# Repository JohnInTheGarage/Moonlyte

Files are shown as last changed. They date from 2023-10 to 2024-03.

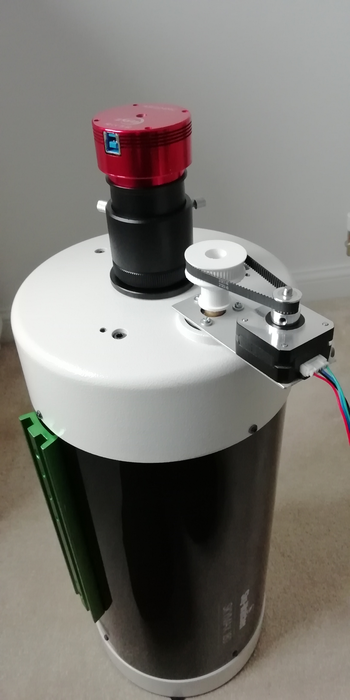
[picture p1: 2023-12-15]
photos etc/HardwareVersion2/BackView.jpg

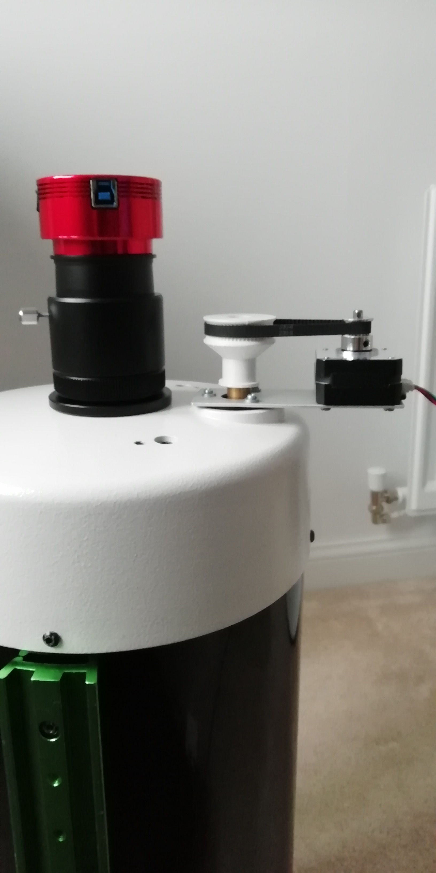
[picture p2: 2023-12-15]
photos etc/HardwareVersion2/SideView.jpg

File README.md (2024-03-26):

# Moonlyte
An electronic focuser for Skywatcher Skymax 180 telescopes, emulating the Moonlite protocol

This project is licensed under the terms of the MIT license.

Written in GO / Tinygo as I had not tried the language much. N.B. you will have to adjust settings.json
as it refers to a location for the GOROOT which is on my disk, not yours.

Uses a Pico microcontroller instead of the traditional Arduino, 
again because I had not used it and it was just collecting dust.  

This implements a basic subset of the Moonlite protocol which I found documented at 
https://indilib.org/media/kunena/attachments/1/HighResSteppermotor107.pdf
(Plus a "debug" output switch.  This is non-standard and should only be used to resolve problems as
it will send text to the host which the host is not expecting.)

Sadly, there is no non-volatile memory on the Pico, so the device will not remember where it was left if you power-off.
I plan to run the focuser back to position zero before power-off as my Host software (Ain Imager & Indigo Framework 
https://www.indigo-astronomy.org/index.html) does not let me use negative numbers for focuser position.  Maybe that's true of all focusers, don't know.

Even more sadly, Tinygo does not implement true concurrency - I had hoped to use the dual processor cores of the Pico, 
with one routine for Comms to the host and the other to drive the stepper but have had to interleave stepping with comms.  
A suitable future update would be to try using the PIO to drive the stepper instead of a separate core.

The physical parts could be improved too. The body is quite fiddly to assemble and prevents manual focusing, but as a first pass its working well.

2023-12-15 Version 2 hardware & slight update for software (mainly prevent "chugging" where the manual input causes the Stepper to be enabled and disabled rapidly)
V2 came about to make room for an Off-Axis Guider.

2024-01-24 Added Intervalometer and bigger box to hold the manual focus and Intervalometer on-off switches

2024-03-26 Added C version of the focuser code for proper multi-threading, reorganised code directories

<pre>
3d printing files Version 1 hardware:
FocuserV5.scad        Design file for Focuser body (OpenSCAD)
FocuserBox.scad       Design file for Box to hold electronics (OpenSCAD)
F.* STL files for the focuser body
</pre>
<pre>
3d printing files Version 2 hardware:
FocuserV6.scad        Design file for Focuser body (OpenSCAD)
FocuserBox.scad       (same as before)
F.* STL files for the focuser body
</pre>

<pre>
Driver module from https://www.amazon.co.uk/dp/B0893DPSJL 
Stepper motor from https://www.amazon.co.uk/dp/B08DCGHLYP. 
</pre>

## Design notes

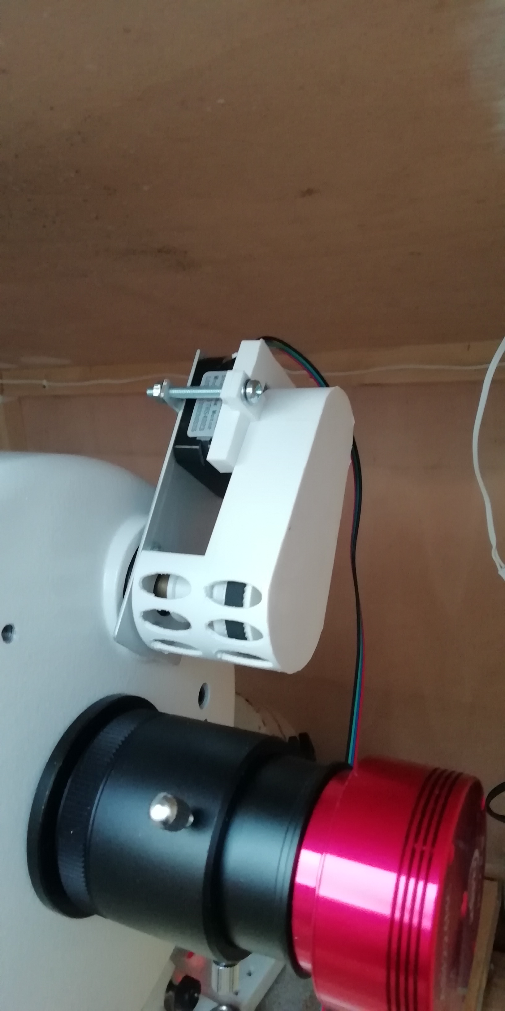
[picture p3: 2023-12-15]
photos etc/HardwareVersion2/WithCover.jpg

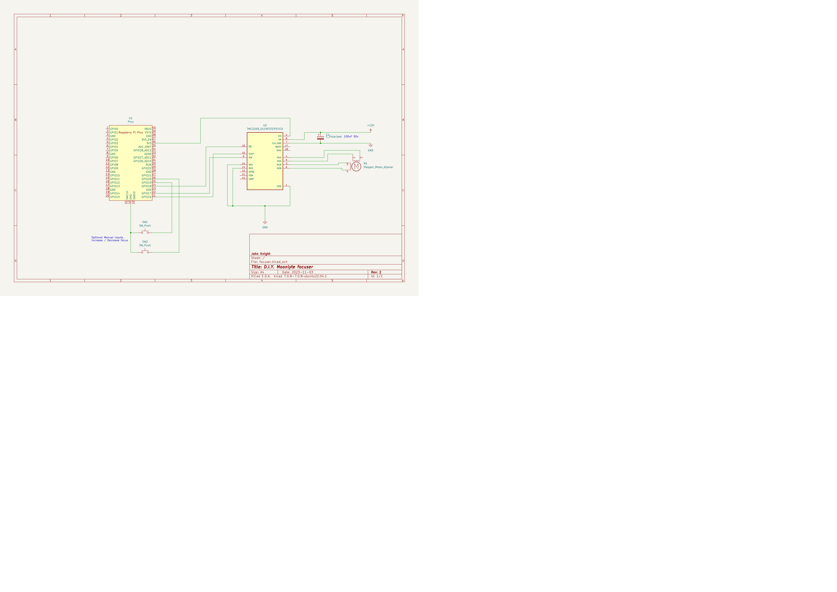
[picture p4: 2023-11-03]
photos etc/CircuitDiagram.png

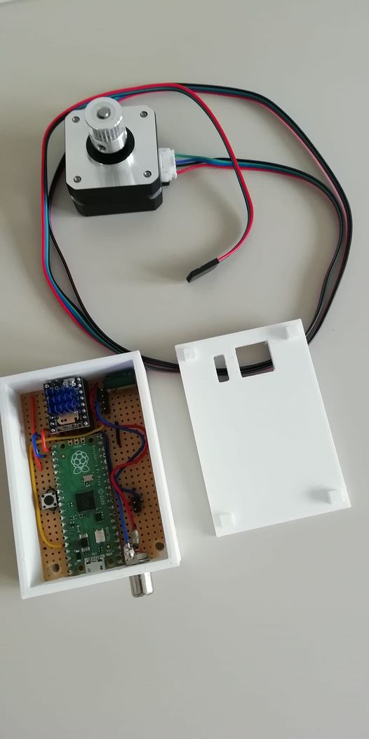
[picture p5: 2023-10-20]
photos etc/Boxview.jpg

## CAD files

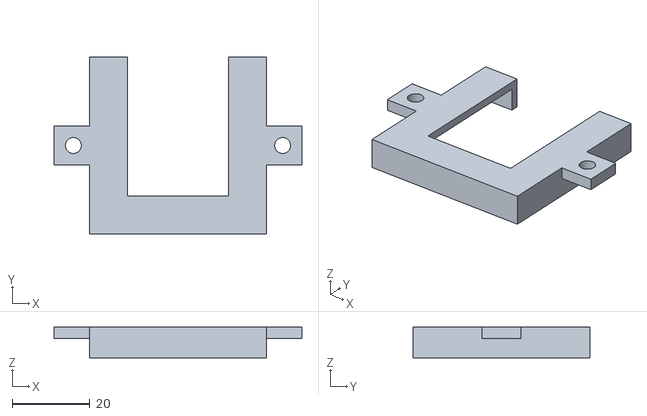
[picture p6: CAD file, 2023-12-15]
3d-printing/V2/FocuserV6StepperFixing.stl
64.0 x 45.7 x 8.00

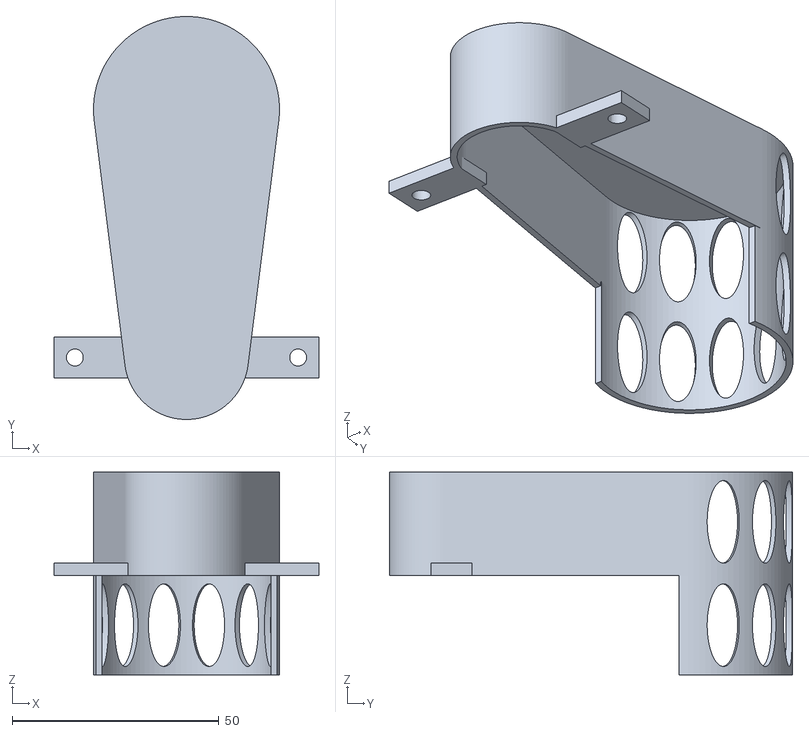
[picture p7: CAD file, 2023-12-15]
3d-printing/V2/FocuserV6Cover.stl
64.0 x 97.5 x 49.0

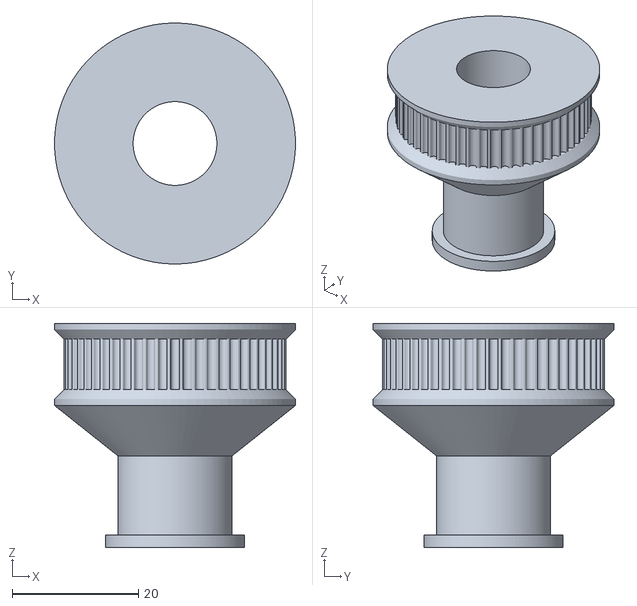
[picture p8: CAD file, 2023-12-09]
3d-printing/V2/Pulley_composer.stl
38.1 x 38.1 x 35.5

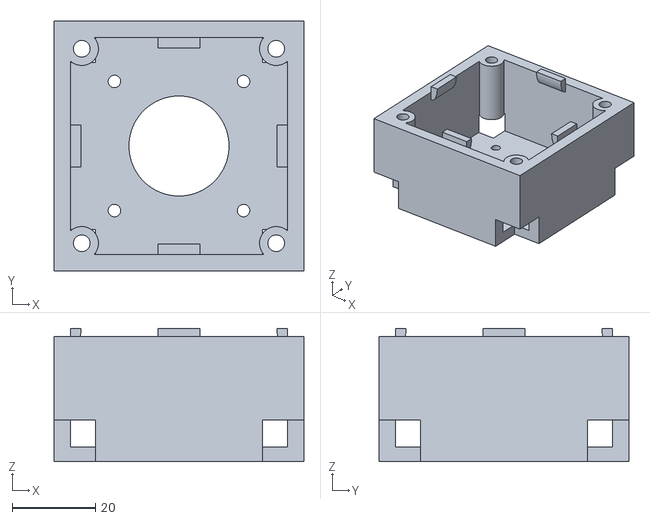
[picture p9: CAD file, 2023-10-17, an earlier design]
3d-printing/V1/F.MainBodyTop.stl
60.0 x 60.0 x 32.0

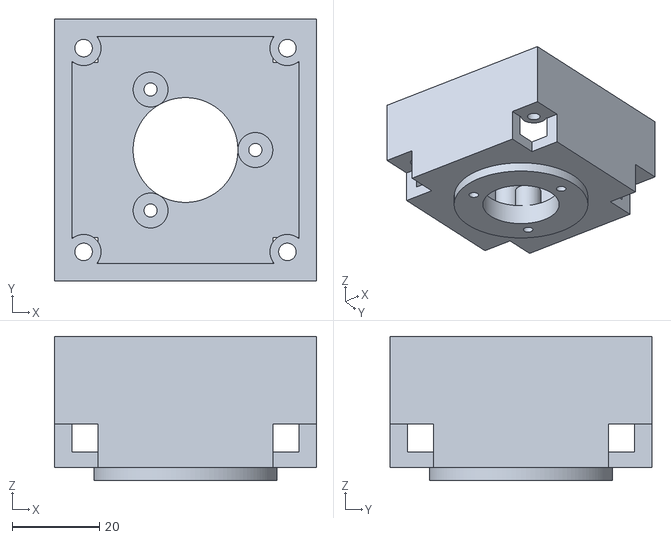
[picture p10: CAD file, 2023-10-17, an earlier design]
3d-printing/V1/F.MainBodyBase.stl
60.0 x 60.0 x 33.0

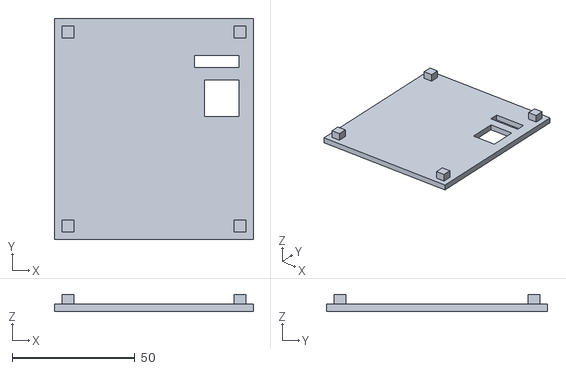
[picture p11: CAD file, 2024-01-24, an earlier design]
3d-printing/V1/FocuserBoxBiggerLid.stl
81.0 x 90.0 x 7.00

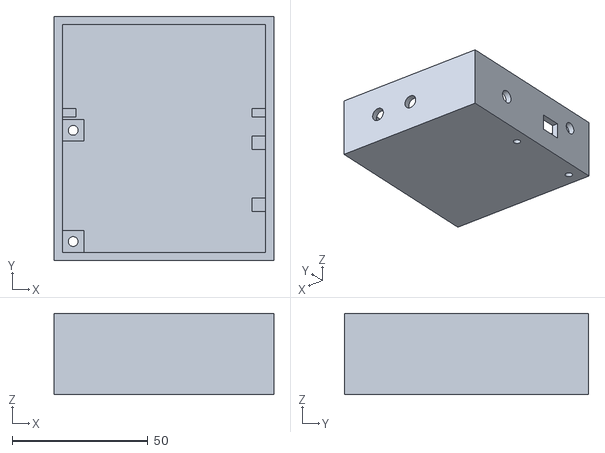
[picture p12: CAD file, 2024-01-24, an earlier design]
3d-printing/V1/FocuserBoxBiggerBase.stl
81.0 x 90.0 x 30.0

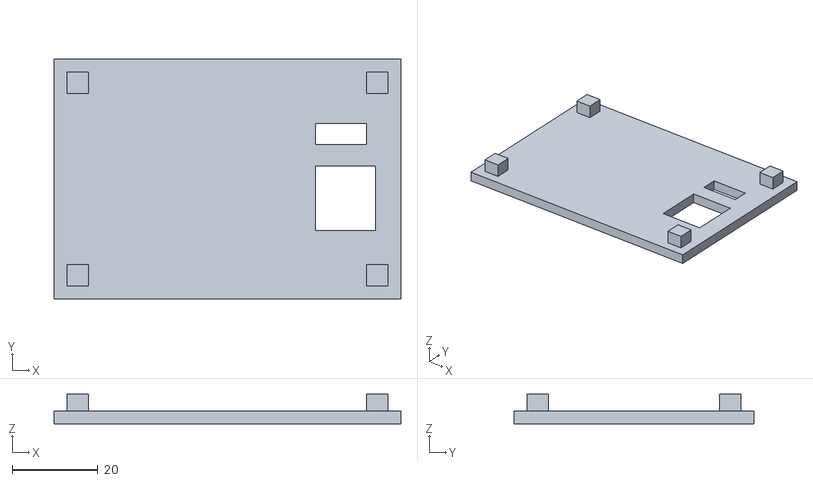
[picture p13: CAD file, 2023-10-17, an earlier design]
3d-printing/V1/FocuserBoxLid.stl
81.0 x 56.0 x 7.00

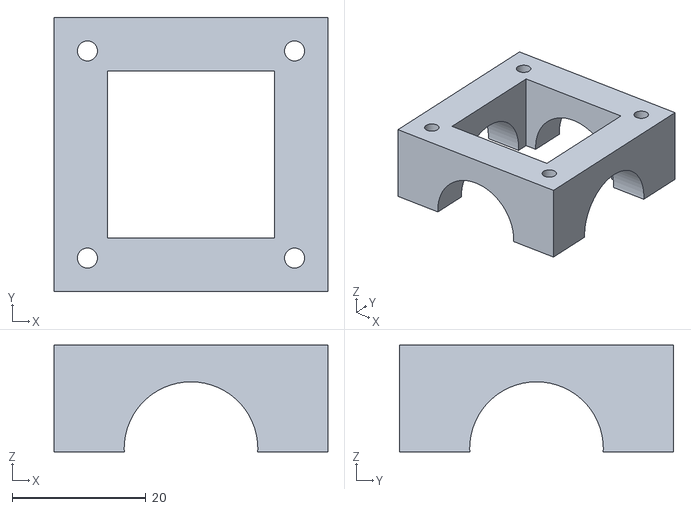
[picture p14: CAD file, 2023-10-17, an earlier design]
3d-printing/V1/F.StepperSupport.stl
41.0 x 41.0 x 16.0

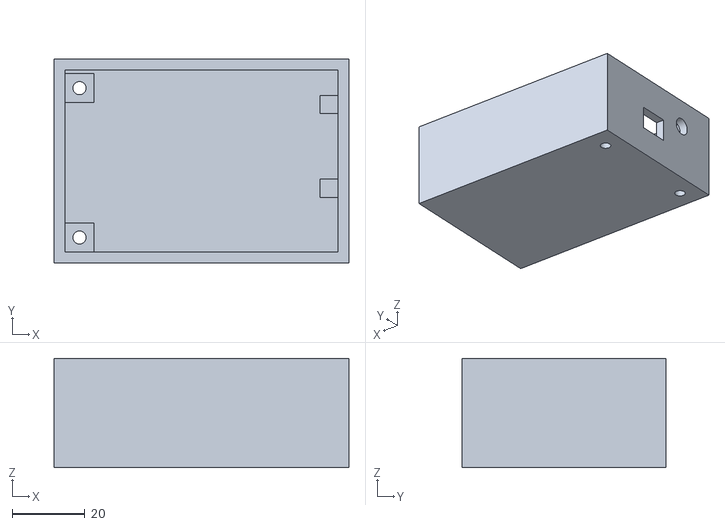
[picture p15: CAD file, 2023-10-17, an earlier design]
3d-printing/V1/FocuserBoxBase.stl
81.0 x 56.0 x 30.0

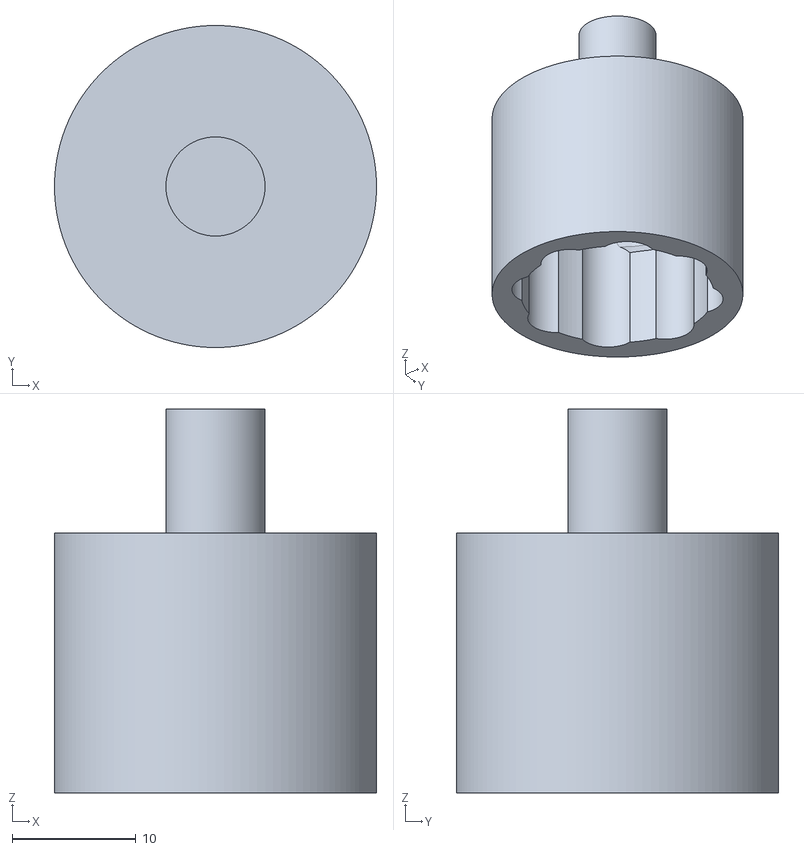
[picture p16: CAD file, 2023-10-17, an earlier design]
3d-printing/V1/F.FocusAttach.stl
26.0 x 26.0 x 31.0

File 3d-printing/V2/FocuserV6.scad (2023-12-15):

//!OpenSCAD

include <Pulley_composer.scad>

/* 
The individual parts can be printed separately by commenting the call to the "assembly()" module, and 
instead adding calls to the relevant parts, i.e. steppersuppport() or mainbodytop() etc.
Some are better printed upside-down.
*/

q=100;      // quality number for cylinders
test=false; // allows looking inside
xpl=0;      // "explodes" the assembly vertically if > zero

coverBigRadius = 22.5;
coverSmallRadius= 15;
stepperSize = 41.5;
printing = true;
// =========================================
module boltBlock(holeSize){
    difference(){
        cube([10,10,3], center=true);
        translate([0,0,-3]){
            cylinder(h=5,d=holeSize, $fn=q);
        }
    }
}

// =========================================
module beltcover(bigC, smallC){
    translate([0,0,-11]){
        linear_extrude(height = 25, center = false, convexity = 10, twist = 0, slices = 20, $fn =q) {
            hull() {
                translate([60,0,0]){ 
                    circle(bigC);
                }
                circle(smallC);
            }
        }
    }
}

// =========================================
module steppermotor(){
    color("silver"){
        cylinder(h=23, d=5, $fn=q);
        cylinder(h=2, d=22, $fn=q);
    }

    color("black"){
        difference(){
            translate([0,0,-11.5]){
                cube([stepperSize,stepperSize,23],center=true);
            }
            if (test){
                translate([-20,-10,-30]){
                   // cube([stepperSize,stepperSize,60]);
                }
            }                
        }
    }
    
}
module cover_ellipseHoles(){
    for(angle = [15 : 30 : 180]){
        rotate([90,0,angle]){
            scale([0.8,2,1]){
                cylinder(h=60,d=10,$fn=q);
            }
        }
    }
}

// =========================================
module cover_CurveUnderPulleyEnd(radius){
    translate([60,0,-35]){
        difference(){
            cylinder(r=radius,h=25,$fn=q);
            translate([0,0,-1]){
                cylinder(r=(radius - 1.5),h=35,$fn=q);
            }
            translate([-35,0,-3]){
                cube(60,center=true);
            }
            translate([0,0,12]){
                cover_ellipseHoles();
            }
            
        }
        
    }
}

// =========================================
module cover_StepperFixing(){
    
    difference(){
        cube([stepperSize +4.2, stepperSize +4.2, 8], center=true);
        translate([0,0,-2]){
            cube([stepperSize +0.2, stepperSize +0.2, 8], center=true);
        }
        translate([-13,-13,-5]){
            cube([40, 26, 12], center=false);
        }
        
//        if (test){
//            translate([-10,-10,-20]){
//                cube([stepperSize,stepperSize,30]);
//            }
//        }                

    }
    translate([0,-27,2.5]){
        boltBlock(4.1);
    }
    translate([0,27,2.5]){
        boltBlock(4.1);
    }

}


// =========================================
module cover(){
    
    difference(){
        beltcover(coverBigRadius, coverSmallRadius);
        translate([0,0,-1.5]){
            beltcover(coverBigRadius-1.5, coverSmallRadius-1.5);
        }
        translate([60,0,2]){
            cover_ellipseHoles();
        }

        if (test){
            translate([-15,0,-15]){
                cube([120,30,50]);
            }
        }
    }

    cover_CurveUnderPulleyEnd(coverBigRadius);
    
    //Bolt holes & their support
    translate([0,0,-9.5]){
        translate([0,-27,0]){
            boltBlock(4.1);
        }
        translate([0,27,0]){
            boltBlock(4.1);
        }
        difference(){
            cube([10,50,3], center=true);
            cube(26, center=true);
        }
    }
    
}


// =========================================
module plate(){
    //----------------------
    module stepperboltholes(){
        translate([15.5,15.5,-10]){
            cylinder(h=40,d=3,$fn=q);
        }
        translate([15.5,-15.5,-10]){
            cylinder(h=40,d=3,$fn=q);
        }
        translate([-15.5,15.5,-10]){
            cylinder(h=40,d=3,$fn=q);
        }
        translate([-15.5,-15.5,-10]){
            cylinder(h=40,d=3,$fn=q);
        }

    }
    //----------------------
    module pulleyholes(){
        for (screw = [90:120:360]) {
            rotate([0,0,screw]){
                translate([16,0,-8]){
                    cylinder(h=20,d=3, $fn=q);
                }
            }
        }
        cylinder(d=17,h=5, $fn=q);

    }


    color("grey"){
        difference(){
            cube([40,107,2]);
        
            translate([20,22.5,-1]){
                stepperboltholes();
            }
            translate([20,83,-1]){
                pulleyholes();
            }
        }
    }
}

//-----------------------------
module flange(){
    rotate([270,0,0]){
        difference(){
            scale([1,2,1]){
                cylinder(h=10, d=5, $fn=30);
            }
            translate([0,-15,-1]){
                cube(30);
            }
            translate([-10,0,-1]){
                cube(30);
            }
            
        }
    }
}

//========================================
//========================================
module assembly(){
if (!printing){
    translate([0,0,24+xpl*2]){
        steppermotor();         // For reference only, not printed
    }
    
    translate([-20,-23,0+xpl]){
        plate();                // For reference only, not printed
    }
    
    translate([0,60,-5-xpl]){
        cylinder(d=13.3,h=25, $fn=q);   // For reference only, not printed
    }
}    
    translate([0,60,7-xpl]){
        // Calling external Pulley_composer.scad, tweaked from the thingyverse download
        //pulley ( "GT2 2mm" , GT2_2mm_pulley_dia , 0.764 , 1.494 );
    }
    
    rotate([0,0,90]){
        translate([0,0,37+xpl]){
        rotate([0,0,0]){
//            cover();
        }
    
    
        translate([0,0,-15]){
            cover_StepperFixing();
        }
    }
}
   
    
}

assembly();

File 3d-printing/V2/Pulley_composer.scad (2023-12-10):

//!OpenSCAD

// 2023-12-09 Tweaked from https://www.thingiverse.com/thing:16627 
// by John Knight to create a pulley for my Moonlyte focuser

// Parametric Pulley with multiple belt profiles
// by droftarts January 2012

// Based on pulleys by:
// http://www.thingiverse.com/thing:11256 by me!
// https://github.com/prusajr/PrusaMendel by Josef Prusa
// http://www.thingiverse.com/thing:3104 by GilesBathgate
// http://www.thingiverse.com/thing:2079 by nophead

// dxf tooth data from http://oem.cadregister.com/asp/PPOW_Entry.asp?company=915217&elementID=07807803/METRIC/URETH/WV0025/F
// pulley diameter checked and modelled from data at http://www.sdp-si.com/D265/HTML/D265T016.html

/**
 * @name Pulley
 * @category Printed
 * @using 1 x m3 nut, normal or nyloc
 * @using 1 x m3x10 set screw or 1 x m3x8 grub screw
 */


// tuneable constants

teeth = 56;			// Number of teeth, standard Mendel T5 belt = 8, gives Outside Diameter of 11.88mm
profile = 12;		// 1=MXL 2=40DP 3=XL 4=H 5=T2.5 6=T5 7=T10 8=AT5 9=HTD_3mm 10=HTD_5mm 11=HTD_8mm 12=GT2_2mm 13=GT2_3mm 14=GT2_5mm

motor_shaft = 13.25;	// NEMA17 motor shaft exact diameter = 5
m3_dia = 3.2;		// 3mm hole diameter
m3_nut_hex = 1;		// 1 for hex, 0 for square nut
m3_nut_flats = 5.7;	// normal M3 hex nut exact width = 5.5
m3_nut_depth = 2.7;	// normal M3 hex nut exact depth = 2.4, nyloc = 4

retainer = 1;		// Belt retainer above teeth, 0 = No, 1 = Yes
retainer_ht = 1.5;	// height of retainer flange over pulley, standard = 1.5
idler = 1;			// Belt retainer below teeth, 0 = No, 1 = Yes
idler_ht = 1.5;		// height of idler flange over pulley, standard = 1.5

pulley_t_ht = 8;	// length of toothed part of pulley, standard = 12
pulley_b_ht = 25;		// pulley base height, standard = 8. Set to same as idler_ht if you want an idler but no pulley.
pulley_b_dia = 18;	// pulley base diameter, standard = 20

no_of_nuts = 0;		// number of captive nuts required, standard = 1
nut_angle = 90;		// angle between nuts, standard = 90
nut_shaft_distance = 1.5;	// distance between inner face of nut and shaft, can be negative.
nut_elevation = pulley_b_ht/2;

//	********************************
//	** Scaling tooth for good fit **
//	********************************
/*	To improve fit of belt to pulley, set the following constant. Decrease or increase by 0.1mm at a time. We are modelling the *BELT* tooth here, not the tooth on the pulley. Increasing the number will *decrease* the pulley tooth size. Increasing the tooth width will also scale proportionately the tooth depth, to maintain the shape of the tooth, and increase how far into the pulley the tooth is indented. Can be negative */

additional_tooth_width = 0.2; //mm

//	If you need more tooth depth than this provides, adjust the following constant. However, this will cause the shape of the tooth to change.

additional_tooth_depth = 0; //mm

// calculated constants


m3_nut_points = 2*((m3_nut_flats/2)/cos(30)); // This is needed for the nut trap

// The following set the pulley diameter for a given number of teeth

MXL_pulley_dia = tooth_spacing (2.032,0.254);
40DP_pulley_dia = tooth_spacing (2.07264,0.1778);
XL_pulley_dia = tooth_spacing (5.08,0.254);
H_pulley_dia = tooth_spacing (9.525,0.381);
T2_5_pulley_dia = tooth_spaceing_curvefit (0.7467,0.796,1.026);
T5_pulley_dia = tooth_spaceing_curvefit (0.6523,1.591,1.064);
T10_pulley_dia = tooth_spacing (10,0.93);
AT5_pulley_dia = tooth_spaceing_curvefit (0.6523,1.591,1.064);
HTD_3mm_pulley_dia = tooth_spacing (3,0.381);
HTD_5mm_pulley_dia = tooth_spacing (5,0.5715);
HTD_8mm_pulley_dia = tooth_spacing (8,0.6858);
GT2_2mm_pulley_dia = tooth_spacing (2,0.254);
GT2_3mm_pulley_dia = tooth_spacing (3,0.381);
GT2_5mm_pulley_dia = tooth_spacing (5,0.5715);

// The following calls the pulley creation part, and passes the pulley diameter and tooth width to that module
/*  moved call of pulley module to FocuserV6.scad - JK
if ( profile == 1 ) { pulley ( "MXL" , MXL_pulley_dia , 0.508 , 1.321 ); }
if ( profile == 2 ) { pulley ( "40 D.P." , 40DP_pulley_dia , 0.457 , 1.226 ); }
if ( profile == 3 ) { pulley ( "XL" , XL_pulley_dia , 1.27, 3.051 ); }
if ( profile == 4 ) { pulley ( "H" , H_pulley_dia ,1.905 , 5.359 ); }
if ( profile == 5 ) { pulley ( "T2.5" , T2_5_pulley_dia , 0.7 , 1.678 ); }
if ( profile == 6 ) { pulley ( "T5" , T5_pulley_dia , 1.19 , 3.264 ); }
if ( profile == 7 ) { pulley ( "T10" , T10_pulley_dia , 2.5 , 6.13 ); }
if ( profile == 8 ) { pulley ( "AT5" , AT5_pulley_dia , 1.19 , 4.268 ); }
if ( profile == 9 ) { pulley ( "HTD 3mm" , HTD_3mm_pulley_dia , 1.289 , 2.27 ); }
if ( profile == 10 ) { pulley ( "HTD 5mm" , HTD_5mm_pulley_dia , 2.199 , 3.781 ); }
if ( profile == 11 ) { pulley ( "HTD 8mm" , HTD_8mm_pulley_dia , 3.607 , 6.603 ); }
if ( profile == 12 ) { pulley ( "GT2 2mm" , GT2_2mm_pulley_dia , 0.764 , 1.494 ); }
if ( profile == 13 ) { pulley ( "GT2 3mm" , GT2_3mm_pulley_dia , 1.169 , 2.31 ); }
if ( profile == 14 ) { pulley ( "GT2 5mm" , GT2_5mm_pulley_dia , 1.969 , 3.952 ); }
*/
// Functions

function tooth_spaceing_curvefit (b,c,d)
	= ((c * pow(teeth,d)) / (b + pow(teeth,d))) * teeth ;

function tooth_spacing(tooth_pitch,pitch_line_offset)
	= (2*((teeth*tooth_pitch)/(3.14159265*2)-pitch_line_offset)) ;

// Main Module

module label(size){
    cube([20,10,1]);
    
    
}

module pulley_base(){
    if ( pulley_b_ht < 2 ) { 
        echo ("CAN'T DRAW PULLEY BASE, HEIGHT LESS THAN 2!!!"); 
    } else {
        // shaft (base) of pulley
        /* Wait, what???? - changing to use cylinder!
        rotate_extrude($fn=pulley_b_dia*4)
        {
                square([pulley_b_dia/2-1,pulley_b_ht]);
                square([pulley_b_dia/2,pulley_b_ht-1]);
                translate([pulley_b_dia/2-1,pulley_b_ht-1]) circle(1);
        }
       */ 
       cylinder(d=pulley_b_dia, h= pulley_b_ht-idler_ht, $fn = 120);
       cylinder(d=pulley_b_dia+4, h= 2, $fn = 120); 
    }
    
    //label();
}

module pulley_teeth(tooth_distance_from_centre, tooth_width_scale, tooth_depth_scale, pulley_OD){

    difference(){
        //shaft - diameter is outside diameter of pulley
        
        translate([0,0,pulley_b_ht]) 
        rotate ([0,0,360/(teeth*4)]) 
        cylinder(r=pulley_OD/2,h=pulley_t_ht, $fn=teeth*4);

        //teeth - cut out of shaft
    
        for(i=[1:teeth]) 
        rotate([0,0,i*(360/teeth)])
        translate([0,-tooth_distance_from_centre,pulley_b_ht -1]) 
        scale ([ tooth_width_scale , tooth_depth_scale , 1 ]) 
        {
            if ( profile == 1 ) { MXL();}
            if ( profile == 2 ) { 40DP();}
            if ( profile == 3 ) { XL();}
            if ( profile == 4 ) { H();}
            if ( profile == 5 ) { T2_5();}
            if ( profile == 6 ) { T5();}
            if ( profile == 7 ) { T10();}
            if ( profile == 8 ) { AT5();}
            if ( profile == 9 ) { HTD_3mm();}
            if ( profile == 10 ) { HTD_5mm();}
            if ( profile == 11 ) { HTD_8mm();}
            if ( profile == 12 ) { GT2_2mm();}
            if ( profile == 13 ) { GT2_3mm();}
            if ( profile == 14 ) { GT2_5mm();}
        }

    }

}

module pulley( belt_type , pulley_OD , tooth_depth , tooth_width )
	{
	echo (str("Belt type = ",belt_type,"; Number of teeth = ",teeth,"; Pulley Outside Diameter = ",pulley_OD,"mm "));
	tooth_distance_from_centre = sqrt( pow(pulley_OD/2,2) - pow((tooth_width+additional_tooth_width)/2,2));
	tooth_width_scale = (tooth_width + additional_tooth_width ) / tooth_width;
	tooth_depth_scale = ((tooth_depth + additional_tooth_depth ) / tooth_depth) ;


//	************************************************************************
//	*** uncomment the following line if pulley is wider than puller base ***
//	************************************************************************

//	translate ([0,0, pulley_b_ht + pulley_t_ht + retainer_ht ]) rotate ([0,180,0])

	difference()
	 {	 
		union()
		{
            pulley_base();
            pulley_teeth(tooth_distance_from_centre, tooth_width_scale, tooth_depth_scale, pulley_OD);
            
			
		//belt retainer / idler
            
		if ( retainer > 0 ) {
            translate ([0,0, pulley_b_ht + pulley_t_ht ]){ 
                cylinder(h=retainer_ht, d1=pulley_OD, d2=pulley_OD + (retainer_ht*2), $fn=90);
                translate([0,0,1.5]){
                    cylinder(h=1, d=pulley_OD + (retainer_ht*2), $fn=90);
                }
            }
        }
		
		if ( idler > 0 ) {
            translate ([0,0, pulley_b_ht -idler_ht]) 
            { 
                cylinder(h=idler_ht, d1=pulley_OD + (idler_ht*2), d2=pulley_OD, $fn=90);
                                translate([0,0,-1]){
                    cylinder(h=1, d=pulley_OD + (retainer_ht*2), $fn=90);
                }

            }
            translate ([0,0, pulley_b_ht -10.5]) 
            { 
                cylinder(h=8, d1=pulley_b_dia, d2=pulley_OD + (idler_ht*2), $fn=90);

            }
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

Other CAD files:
3d-printing/V1/FocuserBox.scad
3d-printing/V1/FocuserBoxBigger.scad
3d-printing/V1/FocuserV5.scad

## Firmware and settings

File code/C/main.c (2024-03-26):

#include <string.h>
#include <stdlib.h>
#include <stdio.h>
#include "pico/multicore.h"
#include "pico/stdlib.h"
#include "hardware/adc.h"
#include "commandhandler.h"
#ifdef PICOW
#include "pico/cyw43_arch.h"
#endif
/*==============================================
* C version of code enables proper multi-threading as both RP2040 cores
* are available for use (unlike in tinygo).  Core-0 handles comms with Host PC
* while core-1 drives the focuser stepper-motor and does the optional
* Intervalometer functions.
*
* Multi-core based on ideas from https://github.com/bnielsen1965 via
* https://www.youtube.com/watch?v=Nz68nY5hzxw
*
* for PICO-W use : cmake -DPICO_BOARD=pico_w ..
* for PICO use   : cmake  ..
* for Intervalometer functions include -DIMAGING=y
==============================================*/

// GPIO Pins & signal values for Stepper control
const uint8_t TMC_STEP = 16;
const uint8_t TMC_DIRECTION = 17;
// Actually its the ENABLE pin but STOPPED reads better.
const uint8_t TMC_STOPPED = 18;
const uint8_t LED_PIN = 25; // for PICO not PICO-W

const uint32_t SIGNAL_STOP = 0x0F0000;
const uint32_t SIGNAL_GO = 0x0A0000;
const uint32_t SIGNAL_BACK1000 = 0x0B0000;

// For manual focus buttons
const uint8_t SW_DECREASE = 19;
const uint8_t SW_INCREASE = 20;

// For Intervalometer
#ifdef IMAGING
const uint8_t SW_IMAGING = 10;
const uint8_t LED_IMAGING = 11;
const uint8_t IMAGING_SECONDS = 60;
const uint8_t IMAGING_PAUSE = 8;
const uint8_t IMAGING_LED_PULSE = 15;   // Micro-seconds.  
const int IMAGING_CLICK_PAUSE = 7300;   // Micro-seconds.  
#endif

// For reading ADC to get temperature
const float TEMP_CONVERSION_FACTOR = 3.3f / (1 << 12);
const float ADC_OFFSET = 0.706;
const float ADC_DIVISOR = 0.001721;

// command inputs etc
const uint8_t MAX_INPUT_LEN = 8;
char command[10];
struct FocuserCommand buildCommand(char *text);

uint32_t locationRequired = 0;
uint32_t locationReported = 0;
uint16_t unusedStepDelay = 0;

//------------------------------
void motorControl();
void checkInput();
int getTemperature();
size_t appendChar(char *buffer, char c);
size_t clearBuffer(char *buffer);
void actionCommand(struct FocuserCommand c);
void initGPIOpins();
//==============================
int main(){
  stdio_init_all();
#ifdef PICOW
  cyw43_arch_init();
#endif
  initGPIOpins();

  // Configure ADC for temperature readings
  adc_init();
  adc_set_temp_sensor_enabled(true);
  adc_select_input(4);

  multicore_launch_core1(motorControl);
  checkInput();
  return 0; // but never
}

//===================================
void checkInput(){
  size_t cursor = 0;

  while (true){
    char ch = getchar_timeout_us(0);
    switch (ch){
    case ':':
      clearBuffer(command);
      break;
    case '#': // end of command
      actionCommand(buildCommand(command));
      break;
    default:
      if ((ch >= '0' && ch <= '9') || (ch >= 'A' && ch <= 'Z'))
      {
        cursor = appendChar(command, ch);
      }
    }
    // Keep an eye on where the stepper is
    if (multicore_fifo_rvalid){
      multicore_fifo_pop_timeout_us(10, &locationReported);
    }

    sleep_ms(10);
  }
}

// append a character to the input buffer and return new length
size_t appendChar(char *buffer, char c){
  if (strlen(buffer) == MAX_INPUT_LEN)
    return MAX_INPUT_LEN;
  buffer[strlen(buffer)] = c;
  return strlen(buffer);
}

// clear contents of the specified buffer
size_t clearBuffer(char *buffer){
  memset(buffer, '\0', MAX_INPUT_LEN);
  return strlen(buffer);
}

//===================================
struct FocuserCommand buildCommand(char *text){

  struct FocuserCommand command;
  clearBuffer(command.action);
  command.value = 0;

  strncpy(command.action, text, 2);

  if (strlen(text) < 3){
    return command;
  }

  char numerics[5]; // Allocate space for substring
  int i;
  for (i = 2; i < 6; i++){ // Copy characters 2..5
    numerics[i - 2] = text[i];
  }
  numerics[4] = '\0'; // Manually add null terminator

  int temp = -1;
  int ix = 0;
  char commandList[] = "SN.SP.YT.YB.DB.SD";
  char thing[3];

  // Check if this command is in the list
  for (ix = 0; ix < 12; ix += 3){
    thing[0] = commandList[ix];
    thing[1] = commandList[ix + 1];
    thing[2] = '\0';
    if (strncmp(command.action, thing, 2) == 0){
      ix = 99;
      command.value = (uint32_t)strtol(numerics, NULL, 16);
    }
  }

  return command;
}

/*
Un-mentioned in the Moonlite protocol is the trick of doubling the temperature
value. The value is halved by the driver at the server end in order to get round
sending floating-point in binary.  Which of course works, only as long as the
resolution for measuring temperature is no better than 0.5 of a degree.
*/
int getTemperature(){
  uint16_t raw = adc_read();
  const float conversion_factor = 3.3f / (1 << 12);
  float result = raw * conversion_factor;
  float temp = 27 - (result - 0.706) / 0.001721;
  //printf("Temp = %f C\n", temp);
  return (int)temp * 2;
}

void initGPIOpins(){
  gpio_init(TMC_STEP);
  gpio_init(TMC_DIRECTION);
  gpio_init(TMC_STOPPED);

  gpio_init(LED_PIN);
  gpio_init(SW_DECREASE);
  gpio_init(SW_INCREASE);

  gpio_set_dir(TMC_STEP, GPIO_OUT);
  gpio_set_dir(TMC_DIRECTION, GPIO_OUT);
  gpio_set_dir(TMC_STOPPED, GPIO_OUT);

  gpio_set_dir(LED_PIN, GPIO_OUT);
  gpio_set_dir(SW_DECREASE, GPIO_IN);
  gpio_set_dir(SW_INCREASE, GPIO_IN);

  gpio_pull_up(SW_DECREASE);
  gpio_pull_up(SW_INCREASE);

#ifdef IMAGING
  gpio_init(SW_IMAGING);
  gpio_init(LED_IMAGING);
  gpio_set_dir(LED_IMAGING, GPIO_OUT);
  gpio_set_dir(SW_IMAGING, GPIO_IN);
  gpio_pull_up(SW_IMAGING);
#endif
}

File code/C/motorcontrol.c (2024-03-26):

#include <stdio.h>
#ifdef PICOW
#include "pico/cyw43_arch.h"
#endif
#include "pico/multicore.h"
#include "pico/stdlib.h"
#include "motorcontrol.h"

//===================================
/*
 * Accepts values via the fifo queue from core-0; usually the next 
 * target focus-position from the * SN command. 
 * When the new value is SIGNAL_STOP, treat as Emergency Stop (from
 * the FQ command). 
 * When the new value is SIGNAL_GO, it is from the FG "Go" command.
 * Also contains optional Intervalometer functions.
 */
void motorControl() {

  stepping = false;
  imagingStarted = false;
  shutterClickRequired = false;
  shutterOpen = false;

  while (true) {

    if (multicore_fifo_rvalid){
      if (multicore_fifo_pop_timeout_us(10, &newInput)){  // microseconds! 
        handleNewInput();
      }
    }
    
    // Do we have one (but not both) buttons pressed?
    if (gpio_get(SW_INCREASE) != gpio_get(SW_DECREASE) ){
      allowManualFocus();
      //Best practise is not to mix manual- and auto- focus but that's up to the user.
    }

    if (stepping) {
      handleStepping();
    } else {
      sleep_ms(50);
      #ifdef IMAGING
      checkImagingSwitch();
      #endif
    }
  }
}

/*
* React to the manual focus buttons being pressed.
*/
void allowManualFocus(){
  
  stepping = true;
  if (gpio_get(SW_INCREASE) == sw_on){
    locationTarget = locationCurrent + 5;
  }

  if (gpio_get(SW_DECREASE) == sw_on){
    if (locationCurrent > 4){
      locationTarget = locationCurrent - 5;
    }
  }
  setStepsDirection();
	sleep_ms(10);  // otherwise it operates very quickly
}
/*
* Drive the stepper motor from locationCurrent to locationTarget.
* Gradual acceleration applied to ease the start-up and hopefully 
* avoid skipping steps, but this is not measured.
* Report back to Core-0 on current location.
*/
void handleStepping(){
  int theseSteps;
  if (locationCurrent != locationTarget) {
    
    theseSteps = stepsReqd;
    if (theseSteps > maxSteps){
      theseSteps = maxSteps;
    }
    stepsReqd -= theseSteps;
    //---------------------------------------
    //printf("at [%d] theseSteps [%d] reqd [%d]\n", locationCurrent, theseSteps, stepsReqd);
    while (theseSteps > 0) {
      theseSteps --;
      gpio_put(TMC_STEP, true);
      sleep_ms(stepDuration);
      gpio_put(TMC_STEP, false);
      sleep_ms(stepDuration);
      locationCurrent += delta;
      // gradual acceleration for stepper
      if (stepDuration > minStepDuration) {
        stepDuration -= 2;
      }
    }
    
    //---------------------------------------
    // Finished these steps, update core-0 with current location.
    if (multicore_fifo_wready){
      multicore_fifo_push_timeout_us(locationCurrent, 10);
    }

  } else {
    if (stepping){
      stepping = false;
      int shortDelay = add_alarm_in_ms(2 * 1000, disableStepper, NULL, false);
      // Now block until we are sure we update current location
      // as Main thread doesn't keep up with the stepper.
      multicore_fifo_push_blocking(locationCurrent);
    }
  }
}

// react to a new value on the FIFO queue
void handleNewInput(){
  // * * * * Emergency stop * * * *
  if (newInput == SIGNAL_STOP) { 
    locationTarget = locationCurrent;
    stepping = false;
    gpio_put(TMC_STOPPED, true);
    return;
  }

  // begin stepping
  if (newInput == SIGNAL_GO) { 
    stepping = true;
    gpio_put(TMC_STOPPED, false);
    stepDuration = maxStepDuration;
    return;
  }

  // Work-around for unknown start point & user forgot to reset 
  // focuser to zero before last power-down.
  if (newInput == SIGNAL_BACK1000) { 
    stepping = true;
    gpio_put(TMC_STOPPED, false);
    locationCurrent = 1000;
    newInput = 0;
    stepDuration = maxStepDuration;
    // don't return, continue below.
  }

  locationTarget = newInput;
  setStepsDirection();

}

void setStepsDirection(){
  if (gpio_get(TMC_STOPPED) == sw_off){
    gpio_put(TMC_STOPPED, sw_on);
  }

  if (locationTarget > locationCurrent) {
    delta = 1;
    gpio_put(TMC_DIRECTION, true);
    stepsReqd = locationTarget - locationCurrent;
  } else {
    delta = -1;
    gpio_put(TMC_DIRECTION, false);
    stepsReqd = locationCurrent - locationTarget;
  }
  //printf("Steps reqd [%d]\n", stepsReqd);
}

/*
* Pause for a few seconds before disabling the stepper.
* Prevents a "chugging" noise during manual focus as the
* stepper is no longer rapidly switched on and off. 
*/
int64_t disableStepper(alarm_id_t id, void *user_data) {
    gpio_put(TMC_STOPPED, true);
    return 0;
}

#ifdef IMAGING
//-----------------------------------------------------------------
// Optional functionality for acting as an Intervalometer
void checkImagingSwitch() {
  if (gpio_get(SW_IMAGING) == sw_on) { 
    if (!imagingStarted){
        imagingStarted = true;
        shutterClickRequired = true;
    }
    
  }
  handleImaging();
}

/*
* Only do anything if the Click required flag is set.
* Click shutter open, wait for <exposure> seconds
* Click shutter closed, wait for <pause> seconds
*/
void handleImaging() {
  if (!shutterClickRequired){
      return;  
  }

  // Always allow shutter to close, but only open if switch is on
  // as imaging can be turned off inside or outside exposure period.
  if (shutterOpen || gpio_get(SW_IMAGING) == sw_on){ 
    fireImagingShutterLED();
    shutterOpen = !shutterOpen;
    //printf("Shutter open :%b\n", shutterOpen);

    // Echo the shutter status with the on-board LED
    #if defined(PICOW)
    cyw43_arch_gpio_put(CYW43_WL_GPIO_LED_PIN, shutterOpen);
    #else
    gpio_put(LED_PIN, shutterOpen);
    #endif
  }

  // Begin an exposure and set delay for the number of seconds required.
  if (shutterOpen){
    int longDelay = add_alarm_in_ms(IMAGING_SECONDS * 1000, triggerShutter, NULL, false);
    return;
  }

 // shutter closed, is it time to stop?
  if (gpio_get(SW_IMAGING) == sw_off) { 
    imagingStarted = false;
    shutterClickRequired = false;
    return;
  }

/*
* Set next shutter Open time to a few seconds after shutter Close time, to allow camera to
* save the RAW image - which takes a short while.
*/
  if (gpio_get(SW_IMAGING) == sw_on) { 
    int shortDelay = add_alarm_in_ms(IMAGING_PAUSE * 1000, triggerShutter, NULL, false);
  }

}

// =============================
/*
* Timings adjusted from https://github.com/MATT-ER-HORN/multiCameraIrControl
* (Canon cameras only, others are available)
* original work (apparently) by Sebastien Setz which seems to be unavailable now
*/
void fireImagingShutterLED() {
  uint8_t i;
  sleep_us(200);                // seems to improve the short sleep timing
  shutterClickRequired = false;
	for (i = 0; i < 16; i++) {
		gpio_put(LED_IMAGING, true);
		sleep_us(IMAGING_LED_PULSE);
		gpio_put(LED_IMAGING, false);
    sleep_us(IMAGING_LED_PULSE);
  }

  sleep_us(IMAGING_CLICK_PAUSE);

  for (i = 0; i < 16; i++) {
		gpio_put(LED_IMAGING, true);
    sleep_us(IMAGING_LED_PULSE);
    gpio_put(LED_IMAGING, false);
    sleep_us(IMAGING_LED_PULSE);
  }
}
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

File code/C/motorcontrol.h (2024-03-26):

extern const uint32_t SIGNAL_STOP;
extern const uint32_t SIGNAL_GO;
extern const uint32_t SIGNAL_BACK1000;
extern const uint8_t TMC_STEP;
extern const uint8_t TMC_STOPPED;
extern const uint8_t TMC_DIRECTION;
extern const uint8_t SW_IMAGING;
extern const uint8_t SW_DECREASE;
extern const uint8_t SW_INCREASE;
extern const uint8_t LED_IMAGING;
extern const uint8_t LED_PIN;
extern const uint8_t IMAGING_SECONDS;
extern const uint8_t IMAGING_PAUSE;
extern const uint8_t IMAGING_LED_PULSE;
extern const int IMAGING_CLICK_PAUSE;

uint32_t locationTarget = 0;
uint32_t locationCurrent = 0;
uint32_t newInput = 0;
int minStepDuration = 2; // milliseconds
int maxStepDuration = 40; // milliseconds
int stepDuration = 0;
int delta = 0;
int maxSteps = 20;
int stepsReqd = 0;

bool stepping;
bool imagingStarted;
bool shutterClickRequired;
bool shutterOpen;

// false = low, i.e. grounded, i.e. switched on (as pull-ups in use)
bool sw_on  = false; 
bool sw_off = true;

void handleImaging();
void handleStepping();
void handleNewInput();
void checkImagingSwitch(); 
void fireImagingShutterLED();
void allowManualFocus();
int checkStepperCooldown(int counter);
void setStepsDirection();
// these are called by alarm timer
int64_t triggerShutter(alarm_id_t id, void *user_data);
int64_t disableStepper(alarm_id_t id, void *user_data);

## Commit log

2023-10-17 add directory for non-code-related files
    [connections.ods]
2023-10-17 added 3dprint files and photos
    [F.FocusAttach.stl, F.MainBodyBase.stl, F.MainBodyTop.stl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]
2023-10-19 circuit diagram added
    [connections.ods]
2023-10-19 adding KiCAD info and image of circuit diagram
    [focuser.kicad_pcb, focuser.kicad_sch]
2023-10-31 Added two buttons for manual focus adjustment
2023-11-03 Updating circuit diagram with the optional manual switches
    [focuser.kicad_sch]
2023-11-03 bug fix - manual adjustment was missing the Enable Stepper part
2023-12-09 Changes for Version 2 of hardware (to allow space for Off-Axis Guider)
    [FocuserV5.scad, Pulley_composer.scad, Pulley_composer.stl]
2023-12-10 updating photos and 3d printing files for new hardware
    [FocuserV6.scad, Pulley_composer.scad]
2023-12-15 Pictures of V2 hardware and software updates for improved performance during manual focusing
    [FocuserV6.scad]
2023-12-15 pictures & stl
    [FocuserV6Cover.stl, FocuserV6StepperFixing.stl]
2023-12-15 separating different hardware versions 3d printer files
    [F.FocusAttach.stl, F.MainBodyBase.stl, F.MainBodyTop.stl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]
2023-12-15 removing old backups made ny KiCad
2023-12-15 removing old backups made by KiCad
2024-01-19 a bigger box to take buttons for manual focus and intervalometer
    [FocuserBoxBigger.scad]
2024-01-24 added Intervalometer function and bigger box to house switches
    [FocuserBoxBigger.scad, FocuserBoxBiggerBase.stl, FocuserBoxBiggerLid.stl]
